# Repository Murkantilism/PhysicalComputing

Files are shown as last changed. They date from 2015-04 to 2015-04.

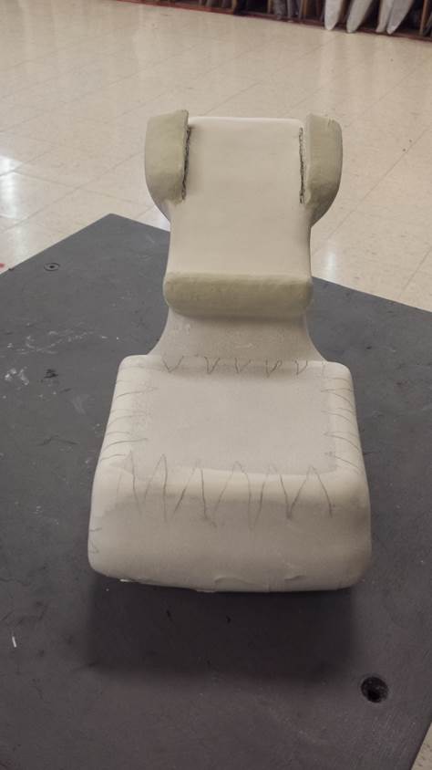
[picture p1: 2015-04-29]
img/model_iteration1_1.jpg

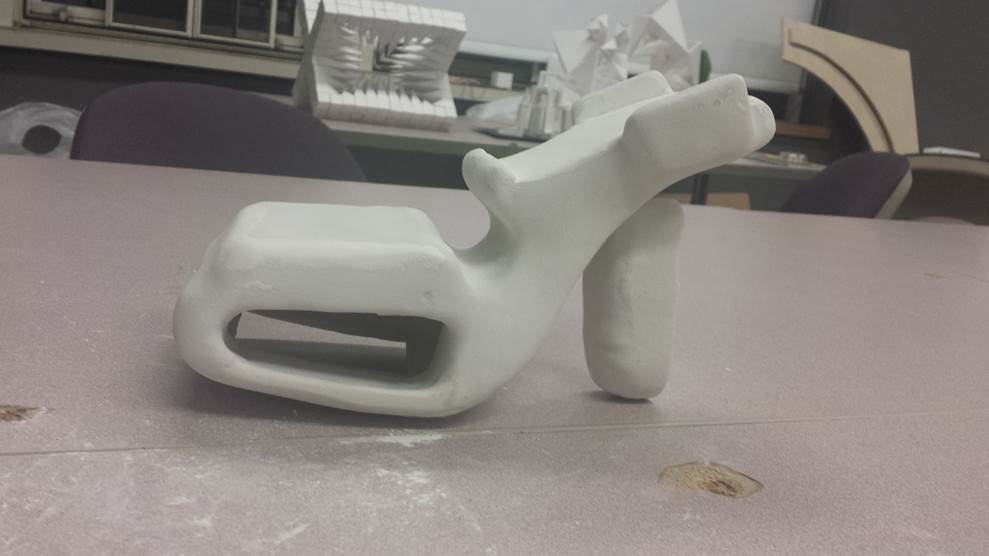
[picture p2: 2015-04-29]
img/model_iteration1_0.jpg

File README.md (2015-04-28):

# Physical Computing Semester Project
The Baby Guardian B9000 - a prototype by Sarah Babski and Deniz Ozkaynak created as the collaborative semester project for the Physical Computing and Physical Design classes at Northeastern University, taught by Mark Sivak and Janos Stone respectively.

# Project Summary
Our container is a tool for a busy and cautious parent to attach to their baby carriage. Using an Arduino Uno and various sensors, we monitor and display important safety metrics for both the child and parent. For the safety of the baby, temperature, wind chill, and UV exposure of the carriage will be monitored. For the safety of the parent - and by extension the baby - heart rate and the carriage's speed will be monitored. It attaches on the handle of the carriage and shows the information on an LCD screen. In addition, there is a phone mount and a small slot to hold the parent’s other necessities.

# Final Circuit Snapshot
See fritzing file for full diagram
Circuit snapshot

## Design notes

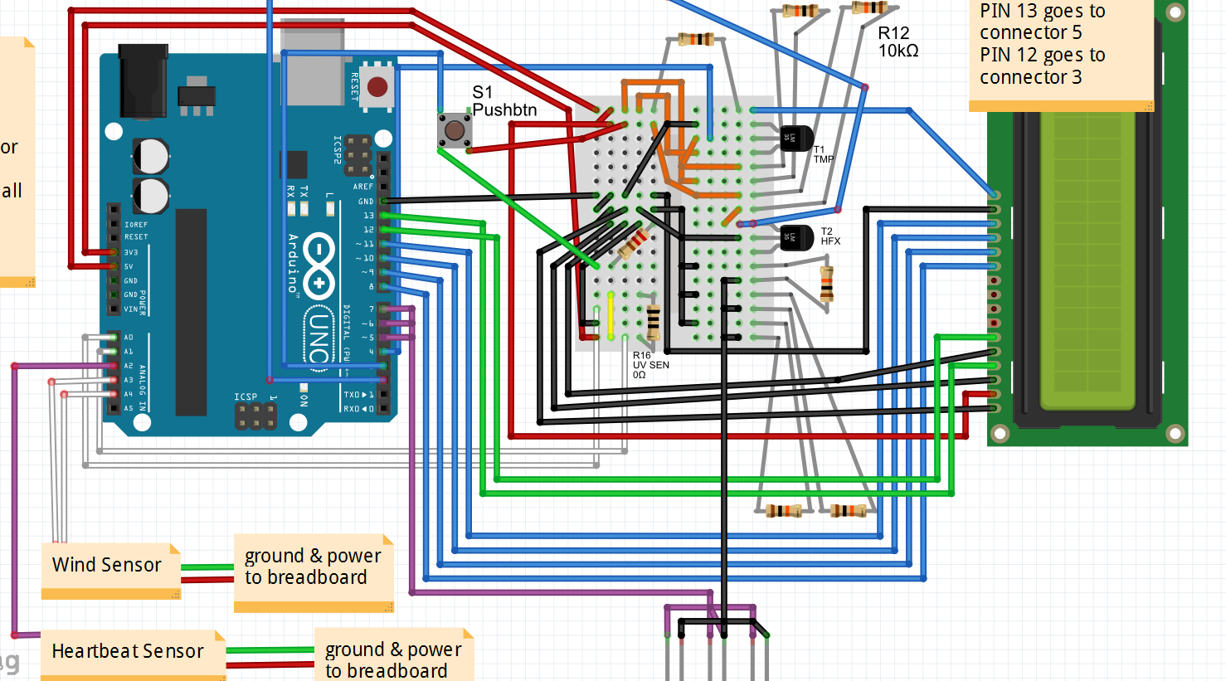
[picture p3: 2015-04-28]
img/circuit_diagram.png

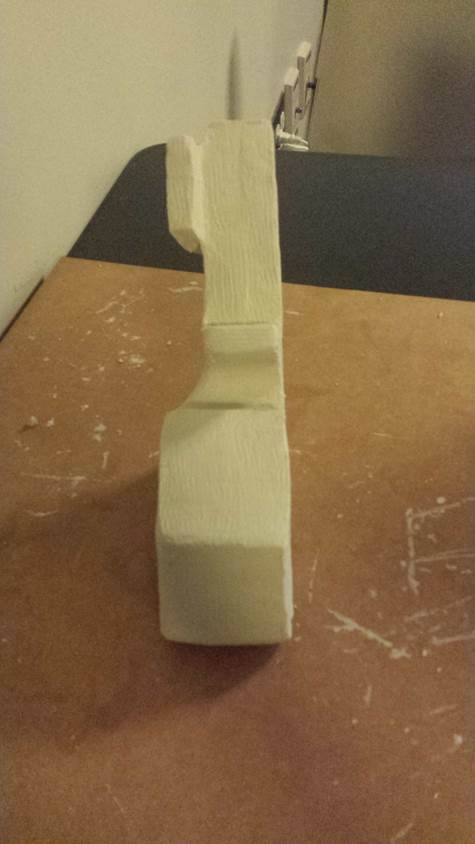
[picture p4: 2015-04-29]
img/model_iteration0_0.jpg

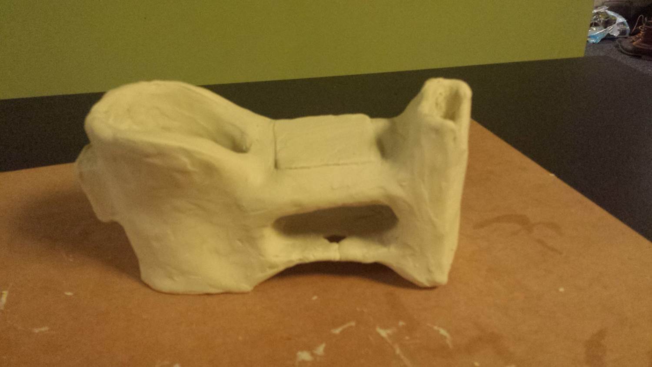
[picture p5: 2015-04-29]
img/model_firstpass.jpg

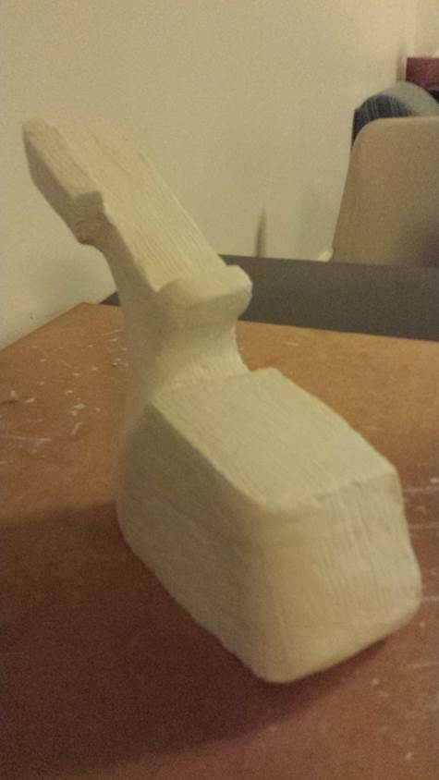
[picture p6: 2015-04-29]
img/model_iteration0_1.jpg

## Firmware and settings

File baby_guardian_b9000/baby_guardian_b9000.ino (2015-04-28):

#include <OneWire.h> 
#include <LiquidCrystal.h>
#include <Interrupt>

boolean DEBUG = false; // Are we in debug mode?

//******************
// Declare i/o vars
//******************
// -TMP sensor vars-
int Din_tmp = 4; // DS18S20 tempt signal pin
// Init LCD library with the numbers of the interface pins
LiquidCrystal lcd(13, 12, 8, 9, 10, 11);
//Temperature chip i/o
OneWire ds(Din_tmp);  // tmp digital pin 2

// -UV sensor vars-
int Aout_UV = A0; // out from uv sensor
int REF_3V3 = A1; // 3.3v power on Arduino
unsigned int last_printed_count;
unsigned int count;
unsigned int last_sensor_reading;

// -Heartbeat sensor vars-
int pulsePin = 2;                 // Pulse Sensor purple wire connected to analog pin 2
int blinkPin = 13;                // pin to blink led at each beat
int fadePin = 5;                  // pin to do fancy classy fading blink at each beat
int fadeRate = 0;                 // used to fade LED on with PWM on fadePin
// these are volatile b/c they are used during the interrupt service routine
volatile int BPM;                 // used to hold the pulse rate
volatile int Signal;              // holds the incoming raw data
volatile int IBI = 600;           // holds the time between beats, the Inter-Beat Interval
volatile boolean Pulse = false;   // true when pulse wave is high, false when it's low
volatile boolean QS = false;      // becomes true when Arduoino finds a beat.

// -Hall Effect sensor vars-
int hallEffectReading = 0;
int previousHallEffectReading = 0;
unsigned long hallEffectMillis;
unsigned long previousHallEffectMillis;
int seconds = 0;
int numHallEffectChangesPerMin = 0;
float carraigeWheelDiameter = 8.0;
int MPH = 0;

// -Wind sensor vars-
#define analogPinForRV    4
#define analogPinForTMP   3
// To calibrate the wind sensor put a glass over it.
// Sensor should not be touching the desktop surface.
// Adjust the zeroWindAdjustment var until sensor reads ~zero w/glass over it
const float zeroWindAdjustment =  .2; // negative numbers yield smaller wind speeds and vice versa.
int TMP_Therm_ADunits;  //temp termistor value from wind sensor
float RV_Wind_ADunits;    //RV output from wind sensor 
float RV_Wind_Volts;
unsigned long lastMillis;
int TempCtimes100;
float zeroWind_ADunits;
float zeroWind_volts;
float WindSpeed_MPH;

// -Pushbutton vars-
int digitalPinPushbutton = 3;
boolean lcd_babydisplayP = true; // Should LCD display baby info?
int buttonPush; // var to read pin status

unsigned long lcdMillis;
unsigned long previousLcdMillis;
int lcdSeconds;

//********************
// Declare satefy vars
//********************
float TMP_WARN_HIGH = 95.0;
float TMP_WARN_LOW = 38.0;
float WIND_WARN = 15.0;
float UV_WARN = 50.0;

void setup(void) {
  Serial.begin(115200);
  //TODO: Investigate what below line is for:
  digitalWrite(2, HIGH);

  // Set up the LCD's number of columns and rows: 
  lcd.begin(16, 2);
  // Set LCD cursor to 0, 0
  lcd.setCursor(0, 0);
  // Print default message to the LCD.
  lcd.print("TMP:");
  lcd.setCursor(10, 0);
  lcd.print("UV:");
  lcd.setCursor(0, 1);
  lcd.print("89BPM");
  lcd.setCursor(11, 1);
  lcd.print("****");

  // Setup UV sensor's pins & vars
  pinMode(Aout_UV, INPUT);
  pinMode(REF_3V3, INPUT);
  last_printed_count = 0;
  count = 0;

  // Setup hall effect's pin
  pinMode(2, OUTPUT);

  pinMode(blinkPin,OUTPUT);         // pin that will blink to your heartbeat!
  pinMode(fadePin,OUTPUT);          // pin that will fade to your heartbeat!
  interruptSetup();                 // sets up to read Pulse Sensor signal every 2mS 
  // UN-COMMENT THE NEXT LINE IF YOU ARE POWERING The Pulse Sensor AT LOW VOLTAGE, 
  // AND APPLY THAT VOLTAGE TO THE A-REF PIN
  //analogReference(EXTERNAL);

  // Setup Wind Sensor's pins
  pinMode(A4, INPUT);        // GND pin      
  pinMode(A3, INPUT);        // VCC pin
  digitalWrite(A3, LOW);     // turn off pullups

  // Setup LED pins
  pinMode(5, OUTPUT); // LED PIN 0 TMP
  pinMode(6, OUTPUT); // LED PIN 1 UV
  pinMode(7, OUTPUT); // LED PIN 2 WIND

  // Setup pushbutton
  pinMode(digitalPinPushbutton, INPUT);
}

void loop(void) {
  // Call helper functions to read WIND, TMP and UV output
  float temperature = getTemp();
  float WindSpeedMPH = windSensor();
  int uvLevel = averageAnalogRead(Aout_UV);
  int refLevel = averageAnalogRead(REF_3V3);
  // Use the 3.3v power pin as a reference to get accurate output from sensor
  float outputVoltage = 3.3 / refLevel * uvLevel;
  // Calculate UV intensity
  float uvIntensity = mapfloat(outputVoltage, 0.99, 2.9, 0.0, 15.0);

  hallEffectReading = digitalRead(2); // Read sensor's pin
  // If reading is different, add 1 to number of changes var
  if(!(previousHallEffectReading == hallEffectReading)){
    numHallEffectChangesPerMin ++;
  }
  
  // Hall effect timer
  hallEffectMillis = millis(); // Record time
  if(hallEffectMillis - previousHallEffectMillis >= 1000){
    seconds  ++; // Increase seconds variable every second
    previousHallEffectMillis = hallEffectMillis;
  }else{
    seconds = 0; // Reset seconds
  }
  
  // Once seconds reaches 60, calculate MPH and reset vars
  if(seconds == 60){
    MPH = calcMPH(numHallEffectChangesPerMin);
    seconds = 0;
    numHallEffectChangesPerMin = 0;
  }
  /*
  // LCD display timer
  lcdMillis = millis();
  if(lcdMillis - previousLcdMillis >= 1000){
    lcdSeconds ++;
    previousLcdMillis = lcdMillis;
  }else{
    lcdSeconds = 0;
  }
  // Once seconds reaches 20, switch display
  if(lcdSeconds == 20){
    lcd_babydisplayP = !lcd_babydisplayP;
    lcdSeconds = 0;
  }*/
  
  // If button is pressed switch displays
  buttonPush = digitalRead(digitalPinPushbutton);
  if(buttonPush == HIGH){
    lcd_babydisplayP = !lcd_babydisplayP;
  }

  if(lcd_babydisplayP == false){
    // TODO: Calculate MPH based on Hall FX instead of 13
    parent(millis()/1000, MPH, BPM);
  }
  else{
    baby(temperature, abs(uvIntensity)*100.0, WindSpeedMPH);
  }

  // Check both high and low satefy levels for temp
  if(temperature > TMP_WARN_HIGH){
    warningLight(5, true);
  }else if (temperature < TMP_WARN_LOW){
    warningLight(5, true);
  }else{
    warningLight(5, false);
  }
  // Check safety levels for UV
  if((abs(uvIntensity)*100.0) > UV_WARN){
    warningLight(6, true);
  }else{
    warningLight(6, false);
  }
  // Check safety levels for wind
  if(WindSpeedMPH < WIND_WARN){
    warningLight(7, true);
  }else{
    warningLight(7, false);
  }

  delay(1000); // Wait a bit, helps refresh rate

  if (DEBUG == true){
    Serial.println(hallEffectReading);

    Serial.print("MP8511 output: ");
    Serial.print(uvLevel);

    Serial.print(" MP8511 voltage: ");
    Serial.print(outputVoltage);

    Serial.print(" UV Intensity (mW/cm^2): ");
    Serial.print(uvIntensity);
  }
  /*
  sendDataToProcessing('S', Signal);     // send Processing the raw Pulse Sensor data
  if (QS == true){                       // Quantified Self flag is true when arduino finds a heartbeat
    fadeRate = 255;                  // Set 'fadeRate' Variable to 255 to fade LED with pulse
    sendDataToProcessing('B',BPM);   // send heart rate with a 'B' prefix
    sendDataToProcessing('Q',IBI);   // send time between beats with a 'Q' prefix
    QS = false;                      // reset the Quantified Self flag for next time    
  }*/

  //TODO: Delete this function?
  ledFadeToBeat();
}

float windSensor(){
  if (millis() - lastMillis > 200){      // read every 200 ms - printing slows this down further

    TMP_Therm_ADunits = analogRead(analogPinForTMP);
    RV_Wind_ADunits = analogRead(analogPinForRV);
    RV_Wind_Volts = (RV_Wind_ADunits *  0.0048828125);

    // these are all derived from regressions from raw data as such they depend on a lot of experimental factors
    // such as accuracy of temp sensors, and voltage at the actual wind sensor, (wire losses) which were unaccouted for.
    TempCtimes100 = (0.005 *((float)TMP_Therm_ADunits * (float)TMP_Therm_ADunits)) - (16.862 * (float)TMP_Therm_ADunits) + 9075.4;  

    zeroWind_ADunits = -0.0006*((float)TMP_Therm_ADunits * (float)TMP_Therm_ADunits) + 1.0727 * (float)TMP_Therm_ADunits + 47.172;  //  13.0C  553  482.39

    zeroWind_volts = (zeroWind_ADunits * 0.0048828125) - zeroWindAdjustment;  

    // This from a regression from data in the form of 
    // Vraw = V0 + b * WindSpeed ^ c
    // V0 is zero wind at a particular temperature
    // The constants b and c were determined by some Excel wrangling with the solver.

    WindSpeed_MPH =  pow(((RV_Wind_Volts - zeroWind_volts) /.2300) , 2.7265);   

    if (DEBUG == true){
      Serial.print("  TMP volts ");
      Serial.print(TMP_Therm_ADunits * 0.0048828125);

      Serial.print(" RV volts ");
      Serial.print((float)RV_Wind_Volts);

      Serial.print("\t  TempC*100 ");
      Serial.print(TempCtimes100 );

      Serial.print("   ZeroWind volts ");
      Serial.print(zeroWind_volts);

      Serial.print("   WindSpeed MPH ");
      Serial.println((float)WindSpeed_MPH);
    }

    lastMillis = millis();
    return (float)WindSpeed_MPH;
  }  
}

//returns the temperature from one DS18S20 in DEG Celsius
float getTemp(){
  byte data[12];
  byte addr[8];

  if ( !ds.search(addr)) {
    //no more sensors on chain, reset search
    ds.reset_search();
    return -1000;
  }

  if ( OneWire::crc8( addr, 7) != addr[7]) {
    Serial.println("CRC is not valid!");
    return -1000;
  }

  if ( addr[0] != 0x10 && addr[0] != 0x28) {
    Serial.print("Device is not recognized");
    return -1000;
  }

  ds.reset();
  ds.select(addr);
  ds.write(0x44,1); // start conversion, with parasite power on at the end

  byte present = ds.reset();
  ds.select(addr);    
  ds.write(0xBE); // Read Scratchpad


  for (int i = 0; i < 9; i++) { // we need 9 bytes
    data[i] = ds.read();
  }

  ds.reset_search();

  byte MSB = data[1];
  byte LSB = data[0];

  float tempRead = ((MSB << 8) | LSB); //using two's compliment
  float TemperatureSum = tempRead / 16;

  return TemperatureSum;
}

//Takes an average of readings on a given pin, returns the average
int averageAnalogRead(int pinToRead)
{
  byte numberOfReadings = 8;
  unsigned int runningValue = 0; 

  for(int x = 0 ; x < numberOfReadings ; x++)
    runningValue += analogRead(pinToRead);
  runningValue /= numberOfReadings;

  return(runningValue);  
}

//The Arduino Map function but for floats, from: http://forum.arduino.cc/index.php?topic=3922.0
float mapfloat(float x, float in_min, float in_max, float out_min, float out_max)
{
  return (x - in_min) * (out_max - out_min) / (in_max - in_min) + out_min;
}

void ledFadeToBeat(){
  fadeRate -= 15;                         //  set LED fade value
  fadeRate = constrain(fadeRate,0,255);   //  keep LED fade value from going into negative numbers!
  analogWrite(fadePin,fadeRate);          //  fade LED
}

// Forwards hearbeat sensor data to processing for visual graphs
void sendDataToProcessing(char symbol, int data ){
  Serial.print(symbol);                // symbol prefix tells Processing what type of data is coming
  Serial.println(data);                // the data to send culminating in a carriage return
}

int calcMPH(int RPM){
  return (int)((((carraigeWheelDiameter * 3.14159265) * RPM) * 60) / 5280);
}

// Switch to the baby's sensor display
void baby(float tmp, float uv, float windspd){
  lcd.clear();
  lcd.setCursor(0, 0);
  lcd.print("TMP:");
  lcd.setCursor(4,0);
  lcd.print(tmp);
  lcd.setCursor(9,0);
  lcd.print((char) 233);

  lcd.setCursor(10, 0);
  lcd.print("UV:");
  lcd.setCursor(13,0);
  lcd.print(uv);

  lcd.setCursor(0, 1);
  lcd.print("WND:");
  lcd.setCursor(4, 1);
  lcd.print(windspd);

  lcd.setCursor(11, 1);
  lcd.print("****");
}
// Switch to the parent's sensor display
void parent(float time, float mph, float bpm){
  lcd.clear();
  lcd.setCursor(0, 0);
  lcd.print(time);
  lcd.setCursor(5, 0);
  lcd.print("s");
  // FIXME: Next two lines temp fix intended to clear random 0's
  lcd.setCursor(6, 0);
  lcd.print("  ");

  lcd.setCursor(9, 0);
  lcd.print(mph);
  lcd.setCursor(13,0);
  lcd.print("MPH");

  lcd.setCursor(0, 1);
  lcd.print(bpm);
  lcd.setCursor(4, 1);
  lcd.print("BPM");

  lcd.setCursor(11, 1);
  lcd.print("****");
}

void warningLight(int lightPin, boolean warning){
  if(warning == true){
    digitalWrite(lightPin, HIGH);
  }else{
    digitalWrite(lightPin, LOW);
  }
}

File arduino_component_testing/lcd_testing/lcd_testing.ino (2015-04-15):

/*
  LiquidCrystal Library - Hello World
 
 Demonstrates the use a 16x2 LCD display.  The LiquidCrystal
 library works with all LCD displays that are compatible with the 
 Hitachi HD44780 driver. There are many of them out there, and you
 can usually tell them by the 16-pin interface.
 
 This sketch prints "Hello World!" to the LCD
 and shows the time.
 
  The circuit:
 * LCD RS pin to digital pin 12
 * LCD Enable pin to digital pin 11
 * LCD D4 pin to digital pin 5
 * LCD D5 pin to digital pin 4
 * LCD D6 pin to digital pin 3
 * LCD D7 pin to digital pin 2
 * LCD R/W pin to ground
 * 10K resistor:
 * ends to +5V and ground
 * wiper to LCD VO pin (pin 3)
 
 Library originally added 18 Apr 2008
 by David A. Mellis
 library modified 5 Jul 2009
 by Limor Fried (http://www.ladyada.net)
 example added 9 Jul 2009
 by Tom Igoe
 modified 22 Nov 2010
 by Tom Igoe
 
 This example code is in the public domain.

 http://www.arduino.cc/en/Tutorial/LiquidCrystal
 */

// include the library code:
#include <LiquidCrystal.h>

float timer = 6000.0;

// initialize the library with the numbers of the interface pins
LiquidCrystal lcd(13, 12, 8, 9, 10, 11);

void setup() {
  // set up the LCD's number of columns and rows: 
  lcd.begin(16, 2);
  // Set cursor to 0, 0
  lcd.setCursor(0, 0);
  // Print a message to the LCD.
  lcd.print("SKYNET ACTIVE");
  lcd.setCursor(0, 1);
  lcd.print("DETONATE:"); 
  lcd.setCursor(10, 1);
  lcd.print(timer - millis()/100);
}

void loop() {
  lcd.setCursor(0, 0);
  // Print a message to the LCD.
  lcd.print("SKYNET ACTIVE");
  lcd.setCursor(0, 1);
  lcd.print("DETONATE:");
  lcd.setCursor(10, 1);
  lcd.print(timer - millis()/100);
}

void baby(){
  lcd.setCursor(0, 0);
  lcd.print("TMP:102F");
  lcd.setCursor(10, 0);
  lcd.print("UV:105");
  lcd.setCursor(0, 1);
  lcd.print("89BPM");
  lcd.setCursor(11, 1);
  lcd.print("****");
}

void parent(){
  lcd.setCursor(0, 0);
  lcd.print(millis()/1000);
  lcd.setCursor(10, 0);
  lcd.print("UV:105");
  lcd.setCursor(0, 1);
  lcd.print("89BPM");
  lcd.setCursor(11, 1);
  lcd.print("****");
}

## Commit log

2015-04-15 Initial commit of all work up to 04/15
    [Deniz Ozkaynak - Circuit Diagram.fzz]
2015-04-22 Large commit, see description
    -All sensors implemented
    -Buttons and LED's implemented
    -Baby/parent switching implemented
    -MPH calculation function added
    -Reorganization of some code, renaming of some variables
    Missing: LED warning light function
    [Deniz Ozkaynak - Circuit Diagram.fzz]
2015-04-22 Minor circuit diagram update
    [Deniz Ozkaynak - Circuit Diagram.fzz]
2015-04-24 Implemented warning lights and safety level checker
    [Deniz Ozkaynak - Circuit Diagram.fzz]
2015-04-24 Fixed pushbtn, see description
    Switched pushbtn to digital pin 3 (from 1) to prevent serial comms
    interruption. Re-implemented pushbtn in code, disabled 20s display
    timer.
    [Deniz Ozkaynak - Circuit Diagram.fzz]
2015-04-28 Final updates to code and circuit diagram
    [Deniz Ozkaynak - Circuit Diagram.fzz]
2015-04-28 Added circuit diagram screenshot
